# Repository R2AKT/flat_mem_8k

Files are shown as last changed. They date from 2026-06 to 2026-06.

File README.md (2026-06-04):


License addendum - https://github.com/R2AKT/flat_mem_8k/blob/main/Addendum.txt
# flat_mem_8k
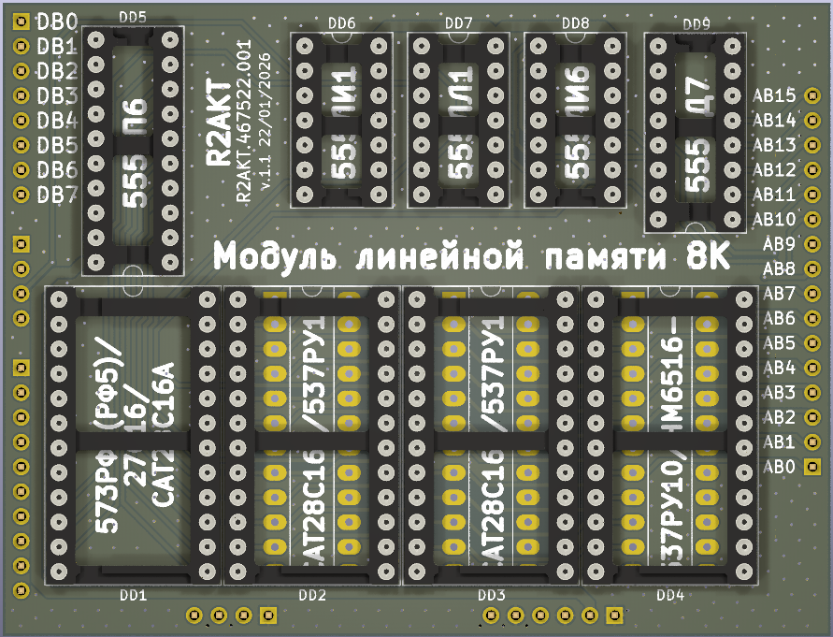
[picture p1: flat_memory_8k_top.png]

8k flat (linear) memory board: 2k ROM + 2k EEPROM/RAM + 2k EEPROM/RAM + 2k RAM.
For Mega-80 (Mega-580) DIY 8-bit micro-computer - https://github.com/R2AKT/Mega-80.

ROM - 2k;
PROM - 4/2k;
RAM - 2/4k.

Status: tested in conjunction with the processor module at a frequency of up to 3 MHz (quartz resonator 27 MHz).

Плата плоской (линейной) памяти на 8к.
Для самодельной 8-битной микро-ЭВМ - https://github.com/R2AKT/Mega-80.

ПЗУ - 2кб;
ППЗУ - 4/2кб;
ОЗУ - 2/4кб.

Статус: проверено совместно с процессорным модулем на частоте до 3 МГц (кварцевый резонатор 27 МГц).

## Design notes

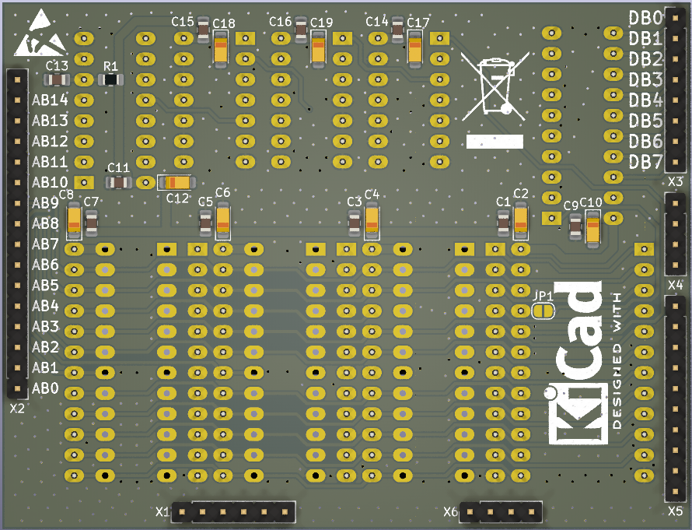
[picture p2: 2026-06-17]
flat_memory_8k_btn.png

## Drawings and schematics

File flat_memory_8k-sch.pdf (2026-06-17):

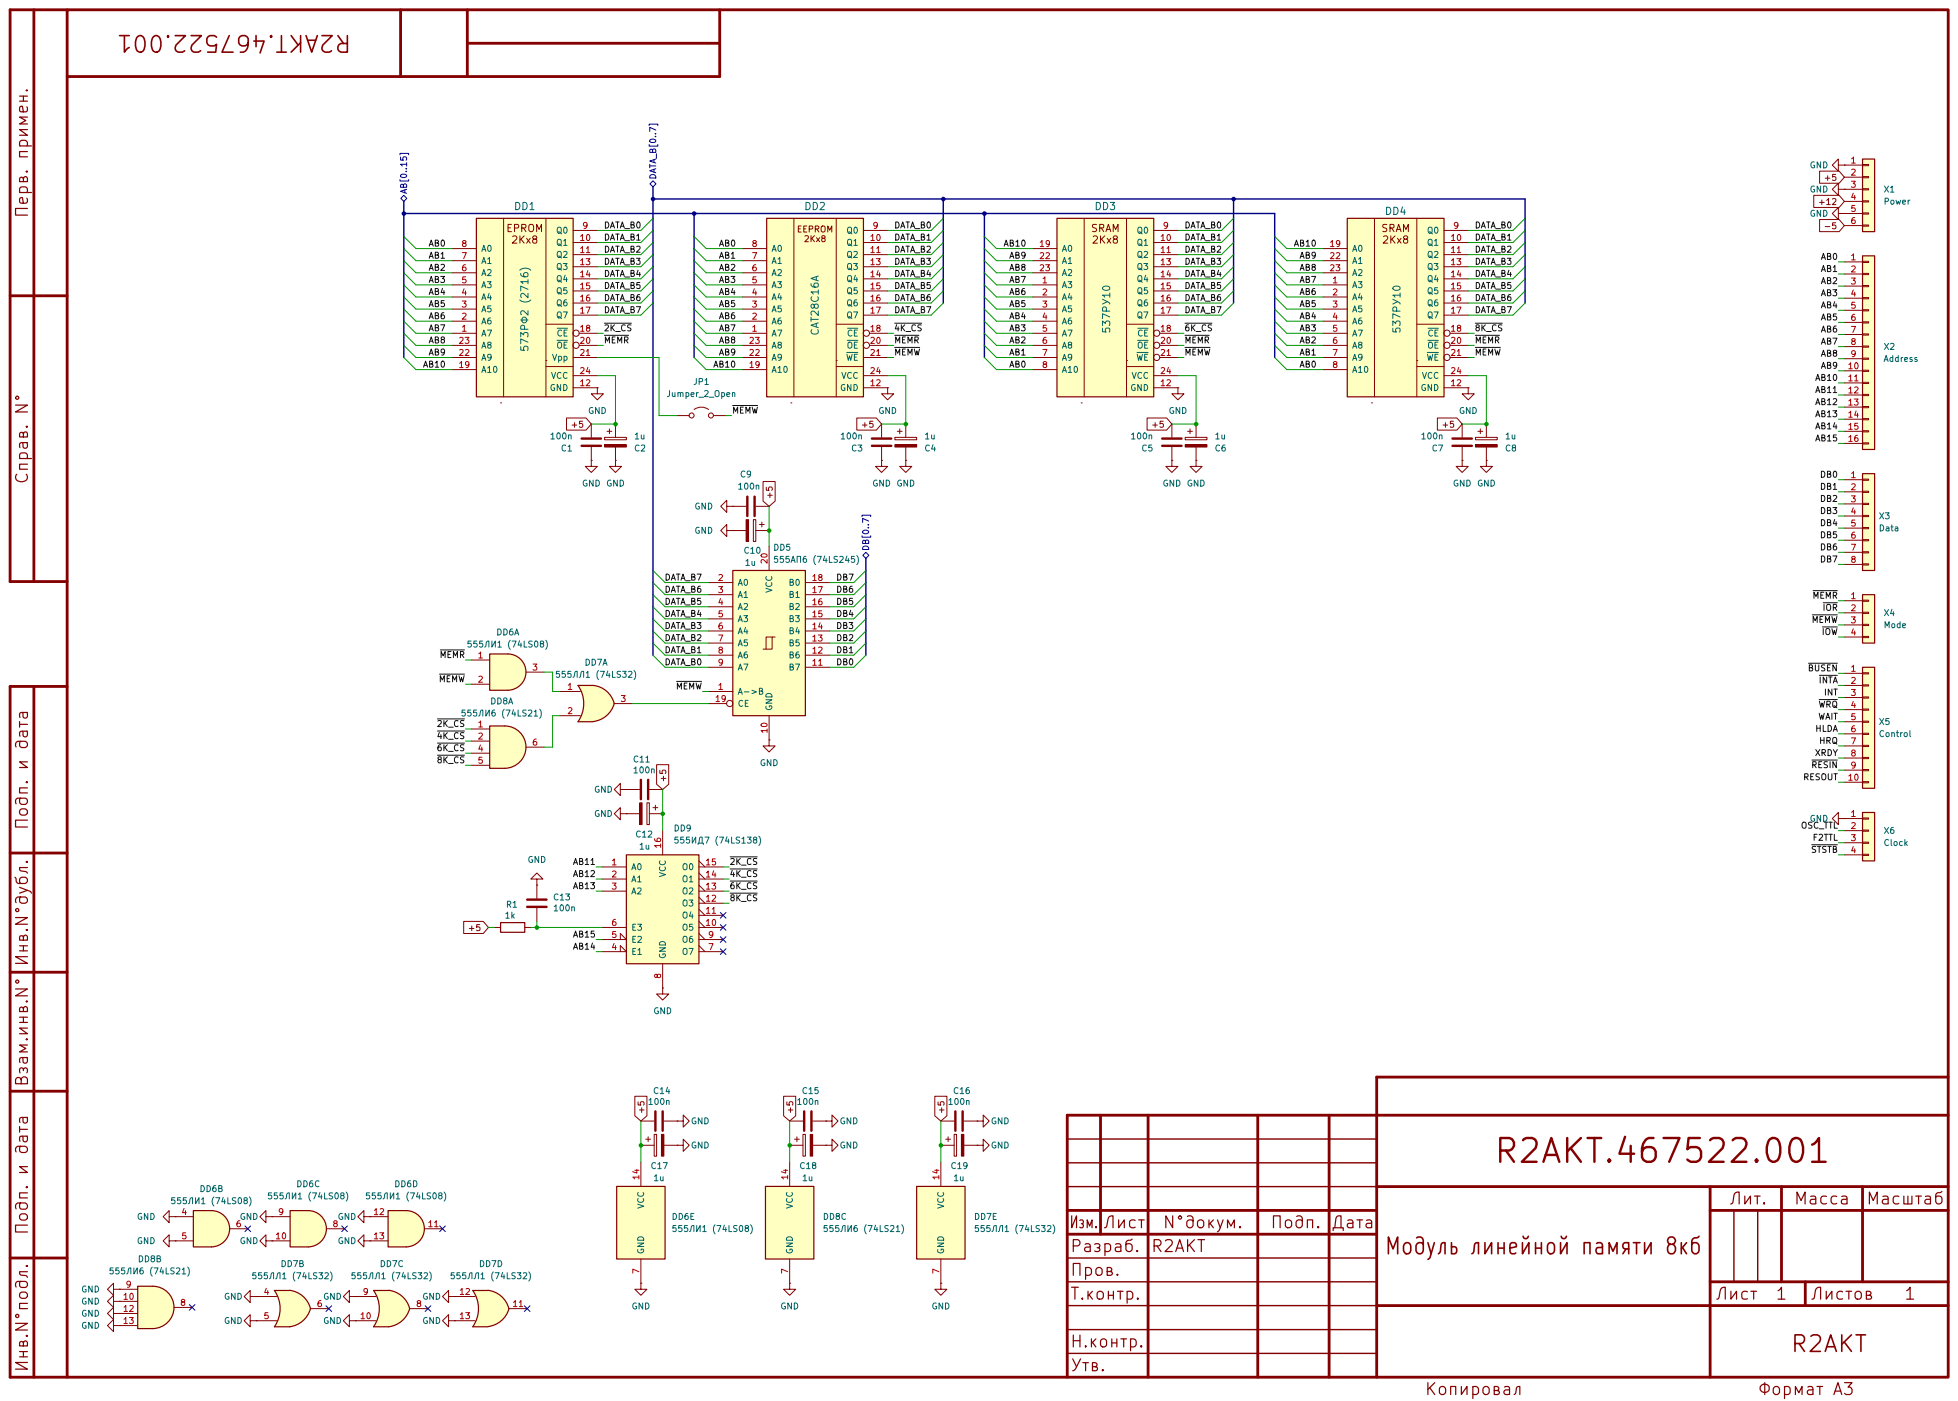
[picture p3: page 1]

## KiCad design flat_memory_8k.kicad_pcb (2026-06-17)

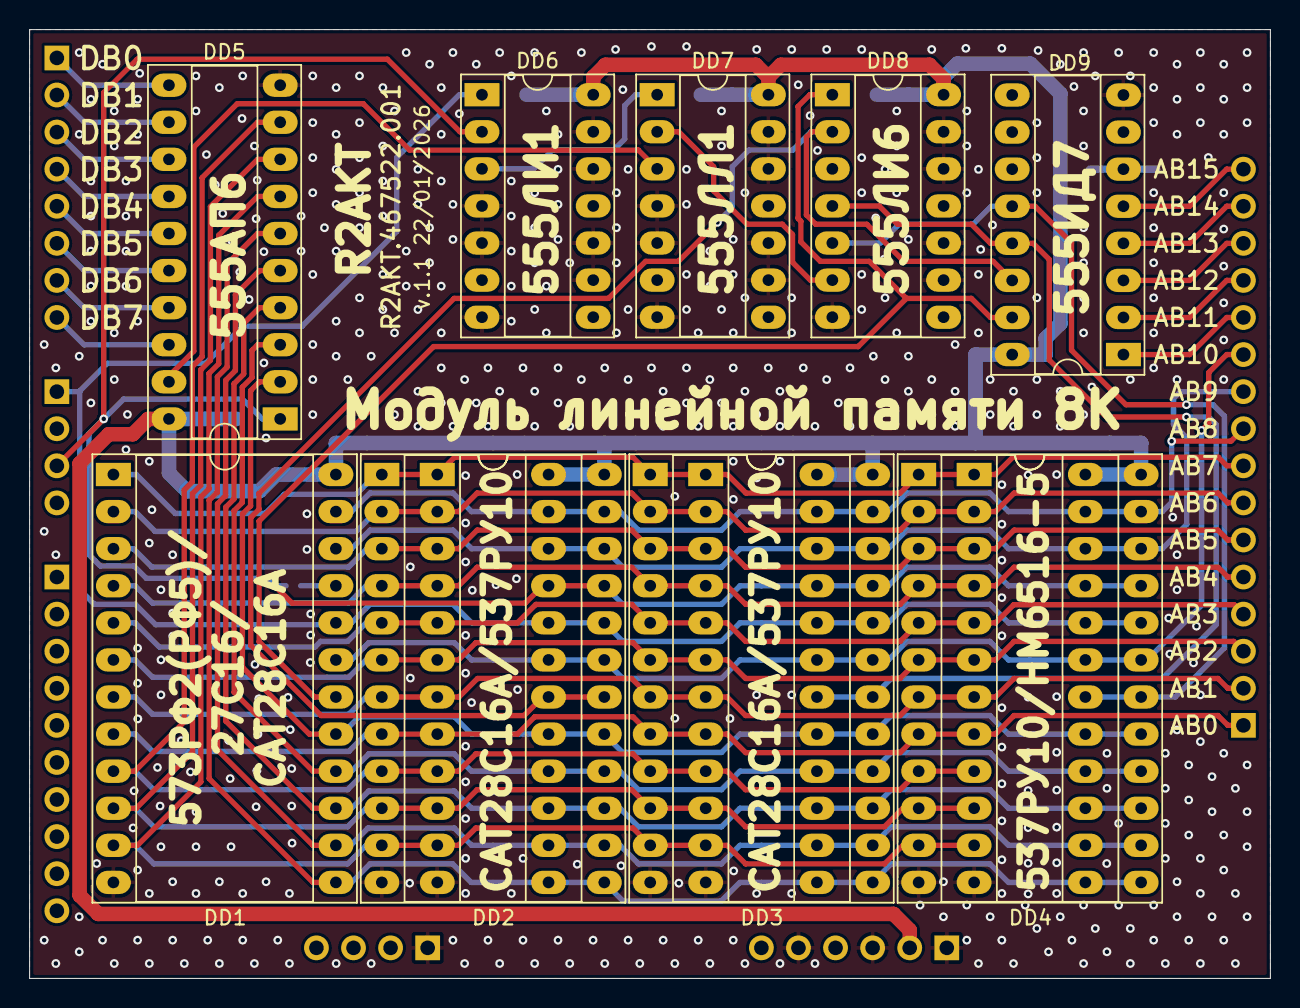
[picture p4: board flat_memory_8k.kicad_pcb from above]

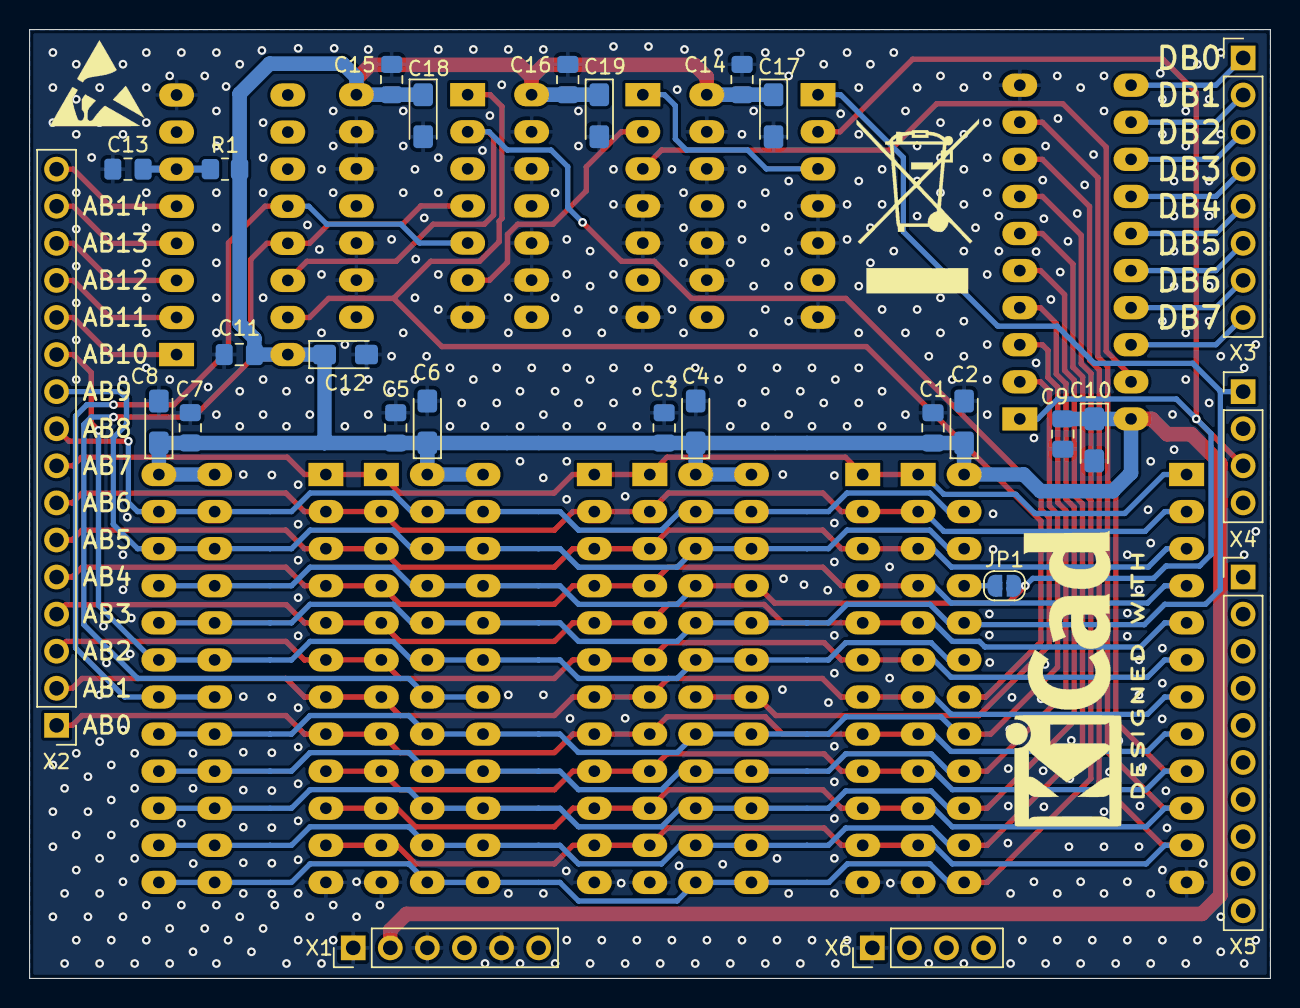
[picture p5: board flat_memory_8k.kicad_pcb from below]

Board: 2 copper layers, 85.0 x 65.0 mm, 39 parts (27 on the bottom side), 45 nets.

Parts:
C1, C3, C5, C7, C9, C11, C13, C14, C15, C16: 100n; C_0805_2012Metric_Pad1.18x1.45mm_HandSolder
C2, C4, C6, C8, C10, C12, C17, C18, C19: 1u; CP_EIA-3216-18_Kemet-A_Pad1.58x1.35mm_HandSolder
DD1: 573РФ2 (2716); DIP-24_W15.24mm_Socket_LongPads
DD2: CAT28C16A; DIP-24_W15.24mm_Socket_LongPads
DD3, DD4: 537РУ10; DIP-24_W15.24mm_Socket_LongPads
DD5: 555АП6 (74LS245); DIP-20_W7.62mm_Socket_LongPads
DD6: 555ЛИ1 (74LS08); DIP-14_W7.62mm_Socket_LongPads
DD7: 555ЛЛ1 (74LS32); DIP-14_W7.62mm_Socket_LongPads
DD8: 555ЛИ6 (74LS21); DIP-14_W7.62mm_Socket_LongPads
DD9: 555ИД7 (74LS138); DIP-16_W7.62mm_Socket_LongPads
DD10, DD11, DD12: DUAL SOCKET; DIP-24_W7.62mm_LongPads
JP1: Jumper_2_Open; SolderJumper-2_P1.3mm_Open_RoundedPad1.0x1.5mm
R1: 1k; R_0805_2012Metric_Pad1.20x1.40mm_HandSolder
X1: Power; PinHeader_1x06_P2.54mm_Vertical
X2: Address; PinHeader_1x16_P2.54mm_Vertical
X3: Data; PinHeader_1x08_P2.54mm_Vertical
X4: Mode; PinHeader_1x04_P2.54mm_Vertical
X5: Control; PinHeader_1x10_P2.54mm_Vertical
X6: Clock; PinHeader_1x04_P2.54mm_Vertical

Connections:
+5: C1.1, C2.1, C3.1, C4.1, C5.1, C6.1, C7.1, C8.1, C9.1, C10.1, C11.1, C12.1, C14.1, C15.1, C16.1, C17.1, C18.1, C19.1, DD1.24 (VCC), DD2.24 (VCC), DD3.24 (VCC), DD4.24 (VCC), DD5.20 (VCC), DD6.14 (VCC), DD7.14 (VCC), DD8.14 (VCC), DD9.16 (VCC), DD10.24 (VCC), DD11.24 (VCC), DD12.24 (VCC), R1.2, X1.2
/AB0: DD1.8 (A0), DD2.8 (A0), DD3.8 (A10), DD4.8 (A10), DD10.8 (A0), DD11.8 (A10), DD12.8 (A10), X2.1
/AB1: DD1.7 (A1), DD2.7 (A1), DD3.7 (A9), DD4.7 (A9), DD10.7 (A1), DD11.7 (A9), DD12.7 (A9), X2.2
/AB2: DD1.6 (A2), DD2.6 (A2), DD3.6 (A8), DD4.6 (A8), DD10.6 (A2), DD11.6 (A8), DD12.6 (A8), X2.3
/AB3: DD1.5 (A3), DD2.5 (A3), DD3.5 (A7), DD4.5 (A7), DD10.5 (A3), DD11.5 (A7), DD12.5 (A7), X2.4
/AB4: DD1.4 (A4), DD2.4 (A4), DD3.4 (A6), DD4.4 (A6), DD10.4 (A4), DD11.4 (A6), DD12.4 (A6), X2.5
/AB5: DD1.3 (A5), DD2.3 (A5), DD3.3 (A5), DD4.3 (A5), DD10.3 (A5), DD11.3 (A5), DD12.3 (A5), X2.6
/AB6: DD1.2 (A6), DD2.2 (A6), DD3.2 (A4), DD4.2 (A4), DD10.2 (A6), DD11.2 (A4), DD12.2 (A4), X2.7
/AB7: DD1.1 (A7), DD2.1 (A7), DD3.1 (A3), DD4.1 (A3), DD10.1 (A7), DD11.1 (A3), DD12.1 (A3), X2.8
/AB8: DD1.23 (A8), DD2.23 (A8), DD3.23 (A2), DD4.23 (A2), DD10.23 (A8), DD11.23 (A2), DD12.23 (A2), X2.9
/AB9: DD1.22 (A9), DD2.22 (A9), DD3.22 (A1), DD4.22 (A1), DD10.22 (A9), DD11.22 (A1), DD12.22 (A1), X2.10
/AB10: DD1.19 (A10), DD2.19 (A10), DD3.19 (A0), DD4.19 (A0), DD10.19 (A10), DD11.19 (A0), DD12.19 (A0), X2.11
/AB11: DD9.1 (A0), X2.12
/AB12: DD9.2 (A1), X2.13
/AB13: DD9.3 (A2), X2.14
/AB14: DD9.4 (E1), X2.15
/AB15: DD9.5 (E2), X2.16
/DATA_B0: DD1.9 (Q0), DD2.9 (Q0), DD3.9 (Q0), DD4.9 (Q0), DD5.9 (A7), DD10.9 (Q0), DD11.9 (Q0), DD12.9 (Q0)
/DATA_B1: DD1.10 (Q1), DD2.10 (Q1), DD3.10 (Q1), DD4.10 (Q1), DD5.8 (A6), DD10.10 (Q1), DD11.10 (Q1), DD12.10 (Q1)
/DATA_B2: DD1.11 (Q2), DD2.11 (Q2), DD3.11 (Q2), DD4.11 (Q2), DD5.7 (A5), DD10.11 (Q2), DD11.11 (Q2), DD12.11 (Q2)
/DATA_B3: DD1.13 (Q3), DD2.13 (Q3), DD3.13 (Q3), DD4.13 (Q3), DD5.6 (A4), DD10.13 (Q3), DD11.13 (Q3), DD12.13 (Q3)
/DATA_B4: DD1.14 (Q4), DD2.14 (Q4), DD3.14 (Q4), DD4.14 (Q4), DD5.5 (A3), DD10.14 (Q4), DD11.14 (Q4), DD12.14 (Q4)
/DATA_B5: DD1.15 (Q5), DD2.15 (Q5), DD3.15 (Q5), DD4.15 (Q5), DD5.4 (A2), DD10.15 (Q5), DD11.15 (Q5), DD12.15 (Q5)
/DATA_B6: DD1.16 (Q6), DD2.16 (Q6), DD3.16 (Q6), DD4.16 (Q6), DD5.3 (A1), DD10.16 (Q6), DD11.16 (Q6), DD12.16 (Q6)
/DATA_B7: DD1.17 (Q7), DD2.17 (Q7), DD3.17 (Q7), DD4.17 (Q7), DD5.2 (A0), DD10.17 (Q7), DD11.17 (Q7), DD12.17 (Q7)
/DB0: DD5.11 (B7), X3.1
/DB1: DD5.12 (B6), X3.2
/DB2: DD5.13 (B5), X3.3
/DB3: DD5.14 (B4), X3.4
/DB4: DD5.15 (B3), X3.5
/DB5: DD5.16 (B2), X3.6
/DB6: DD5.17 (B1), X3.7
/DB7: DD5.18 (B0), X3.8
/~2K_CS: DD1.18 (~CE), DD8.1, DD9.15 (O0)
/~4K_CS: DD2.18 (~CE), DD8.2, DD9.14 (O1), DD10.18 (~CE)
/~6K_CS: DD3.18 (~CE), DD8.4, DD9.13 (O2), DD11.18 (~CE)
/~8K_CS: DD4.18 (~CE), DD8.5, DD9.12 (O3), DD12.18 (~CE)
/~MEMR: DD1.20 (~OE), DD2.20 (~OE), DD3.20 (~OE), DD4.20 (~OE), DD6.1, DD10.20 (~OE), DD11.20 (~OE), DD12.20 (~OE), X4.1
/~MEMW: DD2.21 (~WE), DD3.21 (~WE), DD4.21 (~WE), DD5.1 (A->B), DD6.2, DD10.21 (~WE), DD11.21 (~WE), DD12.21 (~WE), JP1.2 (B), X4.3
GND: C1.2, C2.2, C3.2, C4.2, C5.2, C6.2, C7.2, C8.2, C9.2, C10.2, C11.2, C12.2, C13.1, C14.2, C15.2, C16.2, C17.2, C18.2, C19.2, DD1.12 (GND), DD2.12 (GND), DD3.12 (GND), DD4.12 (GND), DD5.10 (GND), DD6.4, DD6.5, DD6.7 (GND), DD6.9, DD6.10, DD6.12, DD6.13, DD7.4, DD7.5, DD7.7 (GND), DD7.9, DD7.10, DD7.12, DD7.13, DD8.7 (GND), DD8.9, DD8.10, DD8.12, DD8.13, DD9.8 (GND), DD10.12 (GND), DD11.12 (GND), DD12.12 (GND), X1.1, X1.3, X1.5, X6.1
unnamed: DD1.21 (Vpp), JP1.1 (A)
unnamed: DD5.19 (CE), DD7.3
unnamed: DD6.3, DD7.1
unnamed: DD7.2, DD8.6
unnamed: C13.2, DD9.6 (E3), R1.1

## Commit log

2026-01-27 Add files via upload
    Add optional footprint for memory
    Добавлены опциональные посадочные места памяти
    [flat_memory_8k.kicad_pcb, flat_memory_8k.kicad_sch]
2026-06-17 Fix silk
    [flat_memory_8k.kicad_pcb, flat_memory_8k.kicad_sch]

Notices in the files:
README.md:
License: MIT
